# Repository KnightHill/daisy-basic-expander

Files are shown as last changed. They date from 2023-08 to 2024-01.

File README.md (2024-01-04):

# ElectroSmith POD basic expander

[ElectroSmith POD](https://www.electro-smith.com/daisy/pod)

Adds two potentiometers and six buttons to the pod. Check the included KiCad 7 [schematics](hardware) for details.

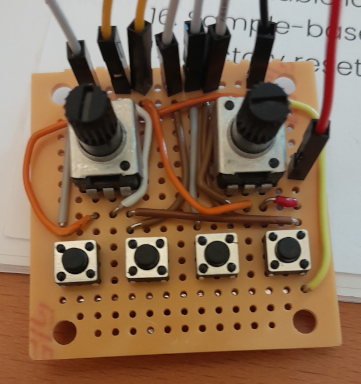
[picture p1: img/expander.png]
Expander bread board


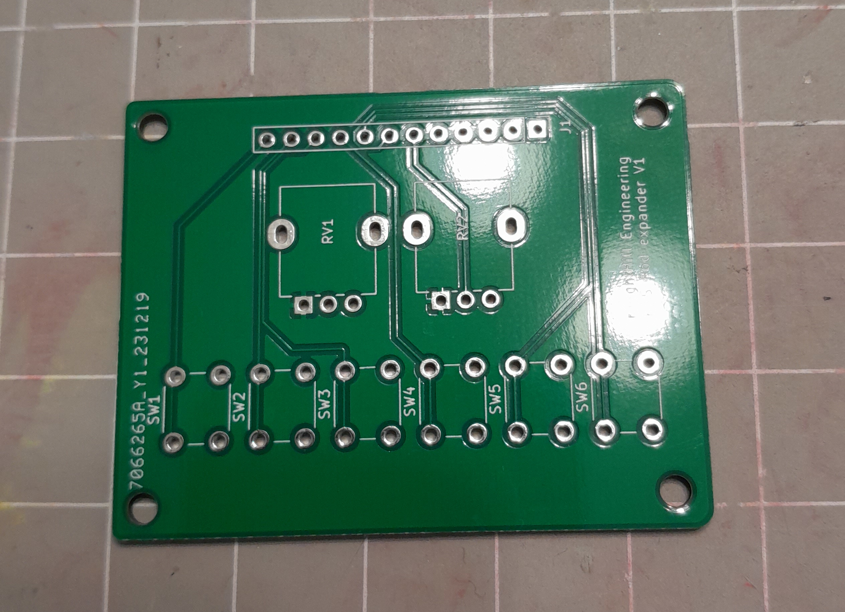
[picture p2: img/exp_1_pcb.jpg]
Expander v1 PCB


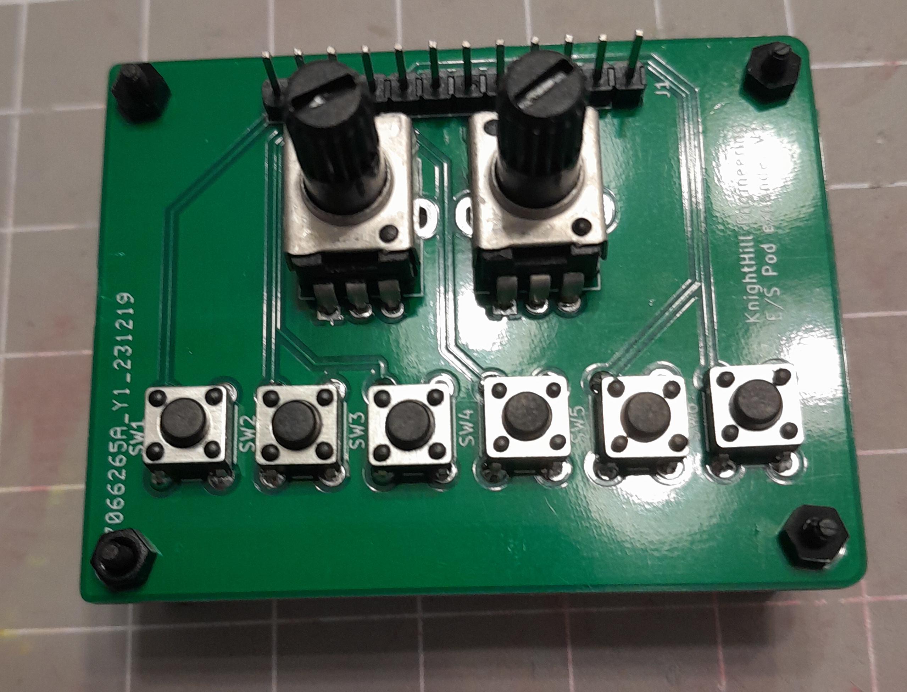
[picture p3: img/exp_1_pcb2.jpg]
Expander v1


 # Disclamer

This is a hobby project. I accept no responsibility for damage to you Daisy Seed, external equipment or anything else. You use this code and harware at your own risk.

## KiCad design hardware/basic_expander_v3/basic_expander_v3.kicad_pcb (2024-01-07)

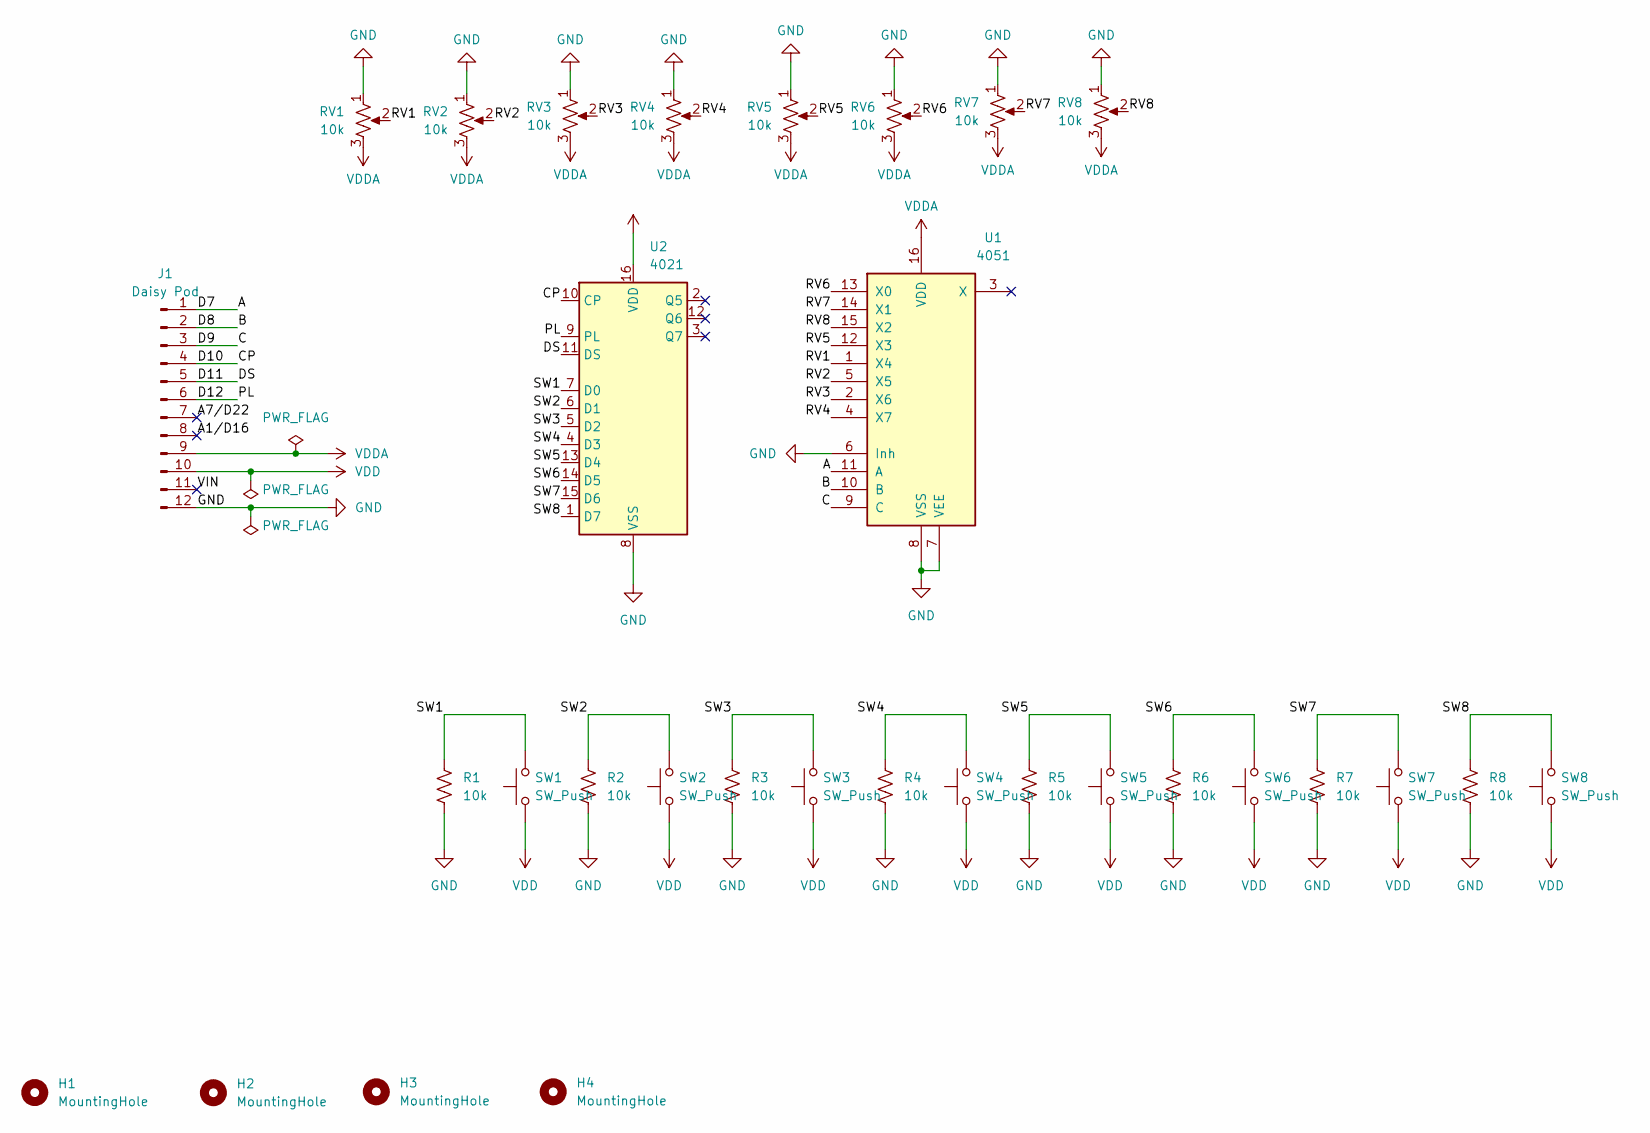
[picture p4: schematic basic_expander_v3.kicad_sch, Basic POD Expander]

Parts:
H1, H2, H3, H4: MountingHole; MountingHole_2.2mm_M2
J1: Daisy Pod; PinHeader_1x12_P2.54mm_Vertical
R1, R2, R3, R4, R5, R6, R7, R8: 10k; R_Axial_DIN0207_L6.3mm_D2.5mm_P7.62mm_Horizontal
RV1, RV2, RV3, RV4, RV5, RV6, RV7, RV8: 10k; Potentiometer_Alpha_RD901F-40-00D_Single_Vertical
SW1, SW2, SW3, SW4, SW5, SW6, SW7, SW8: SW_Push; SW_PUSH_6mm
U1: 4051; DIP-16_W7.62mm
U2: 4021; DIP-16_W7.62mm

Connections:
/A: J1.1, U1.11 (A)
/A1/D16: J1.8
/A7/D22: J1.7
/B: J1.2, U1.10 (B)
/C: J1.3, U1.9 (C)
/CP: J1.4, U2.10 (CP)
/D11: J1.5, U2.11 (DS)
/D12: J1.6, U2.9 (PL)
/RV1: RV1.2, U1.1 (X4)
/RV2: RV2.2, U1.5 (X5)
/RV3: RV3.2, U1.2 (X6)
/RV4: RV4.2, U1.4 (X7)
/RV5: RV5.2, U1.12 (X3)
/RV6: RV6.2, U1.13 (X0)
/RV7: RV7.2, U1.14 (X1)
/RV8: RV8.2, U1.15 (X2)
/SW1: R1.1, SW1.2, U2.7 (D0)
/SW2: R2.1, SW2.2, U2.6 (D1)
/SW3: R3.1, SW3.2, U2.5 (D2)
/SW4: R4.1, SW4.2, U2.4 (D3)
/SW5: R5.1, SW5.2, U2.13 (D4)
/SW6: R6.1, SW6.2, U2.14 (D5)
/SW7: R7.1, SW7.2, U2.15 (D6)
/SW8: R8.1, SW8.2, U2.1 (D7)
/VIN: J1.11
GND: J1.12, R1.2, R2.2, R3.2, R4.2, R5.2, R6.2, R7.2, R8.2, RV1.1, RV2.1, RV3.1, RV4.1, RV5.1, RV6.1, RV7.1, RV8.1, U1.6 (Inh), U1.7 (VEE), U1.8 (VSS), U2.8 (VSS)
VDD: J1.10, SW1.1, SW2.1, SW3.1, SW4.1, SW5.1, SW6.1, SW7.1, SW8.1, U2.16 (VDD)
VDDA: J1.9, RV1.3, RV2.3, RV3.3, RV4.3, RV5.3, RV6.3, RV7.3, RV8.3, U1.16 (VDD)

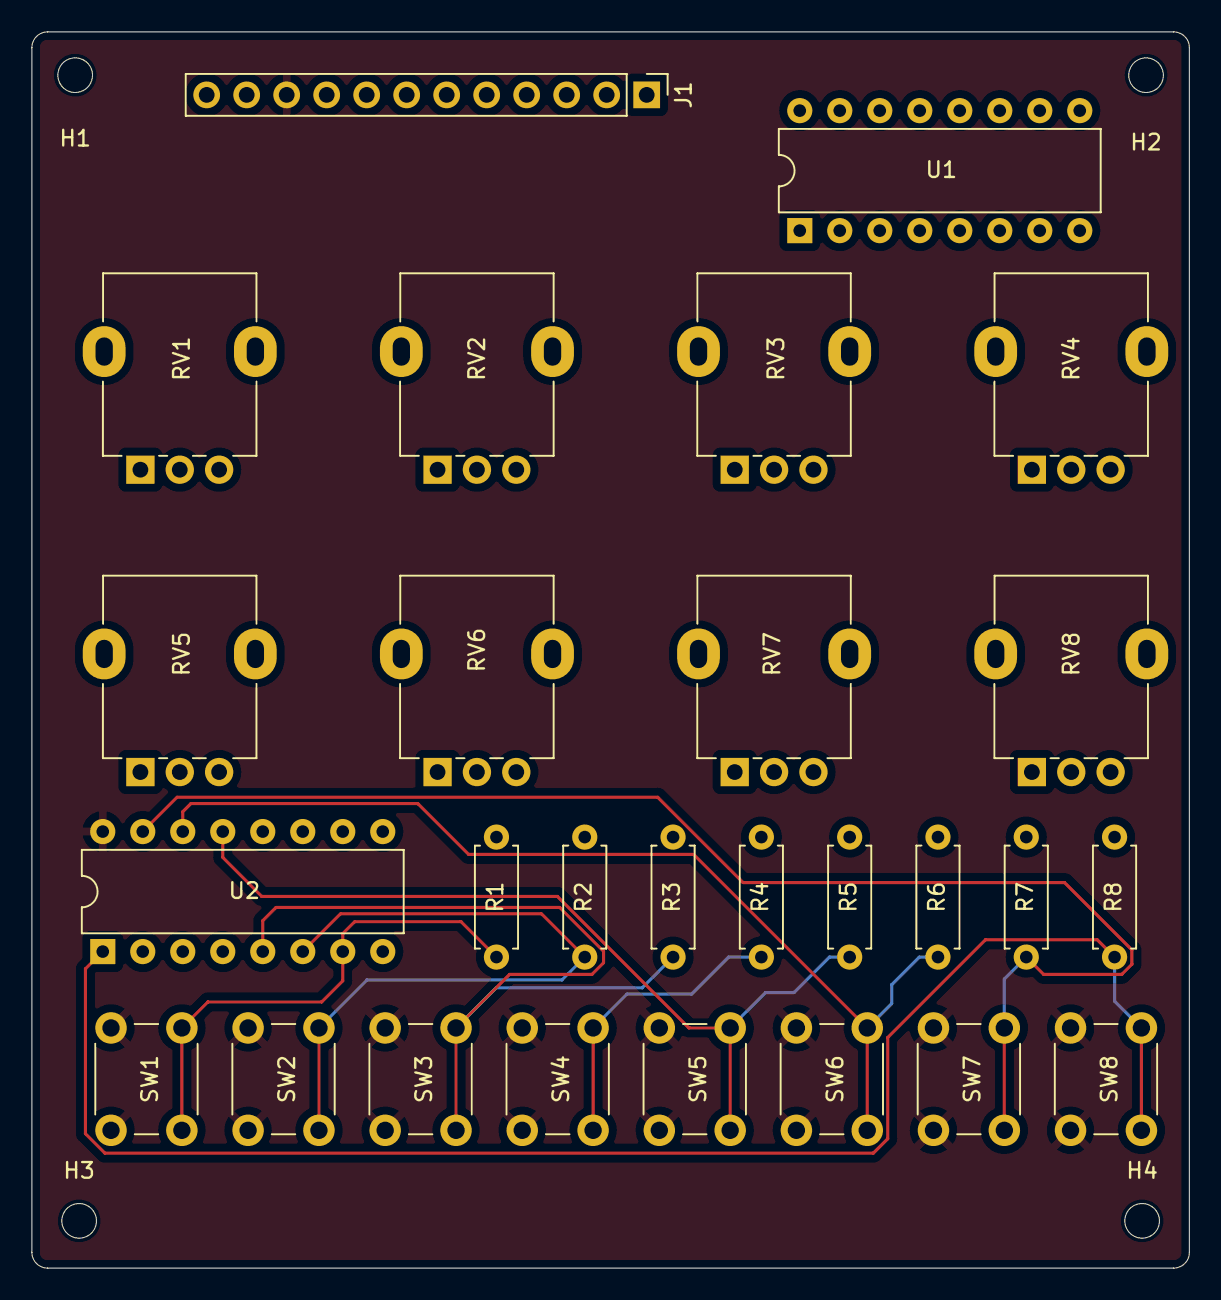
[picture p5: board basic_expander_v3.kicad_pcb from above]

Board: 2 copper layers, 73.5 x 78.5 mm, 31 parts (0 on the bottom side), 25 nets.

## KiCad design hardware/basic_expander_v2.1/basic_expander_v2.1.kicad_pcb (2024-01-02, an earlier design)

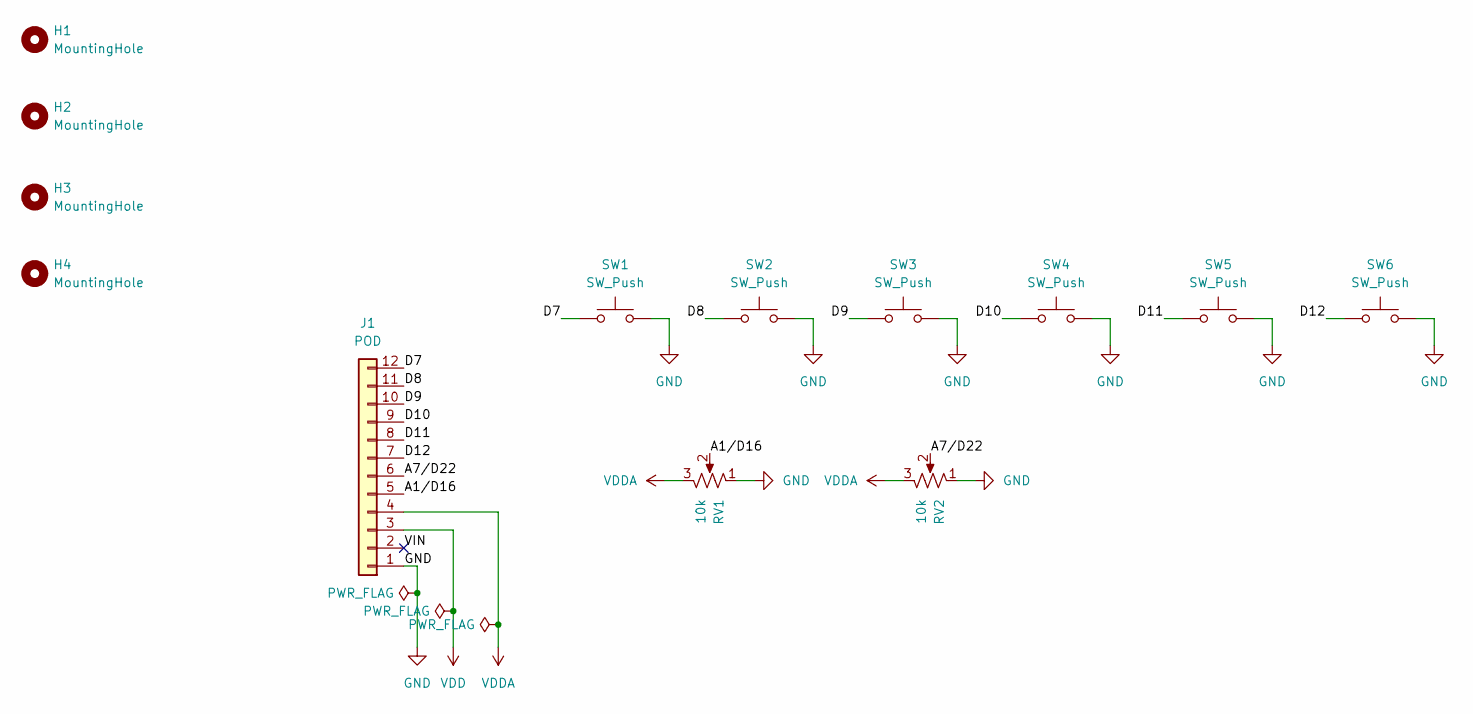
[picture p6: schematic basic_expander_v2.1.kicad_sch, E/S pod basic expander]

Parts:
H1, H2, H3, H4: MountingHole; MountingHole_2.2mm_M2
J1: POD; PinHeader_1x12_P2.54mm_Vertical
RV1, RV2: 10k; Potentiometer_uxcel_9mm_Single_Vertical
SW1, SW2, SW3, SW4, SW5, SW6: SW_Push; SW_PUSH_6mm

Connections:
/A1/D16: J1.5, RV1.2
/A7/D22: J1.6, RV2.2
/D7: J1.12, SW1.1
/D8: J1.11, SW2.1
/D9: J1.10, SW3.1
/D10: J1.9, SW4.1
/D11: J1.8, SW5.1
/D12: J1.7, SW6.1
/VIN: J1.2
GND: J1.1, RV1.1, RV2.1, SW1.2, SW2.2, SW3.2, SW4.2, SW5.2, SW6.2
VDD: J1.3
VDDA: J1.4, RV1.3, RV2.3

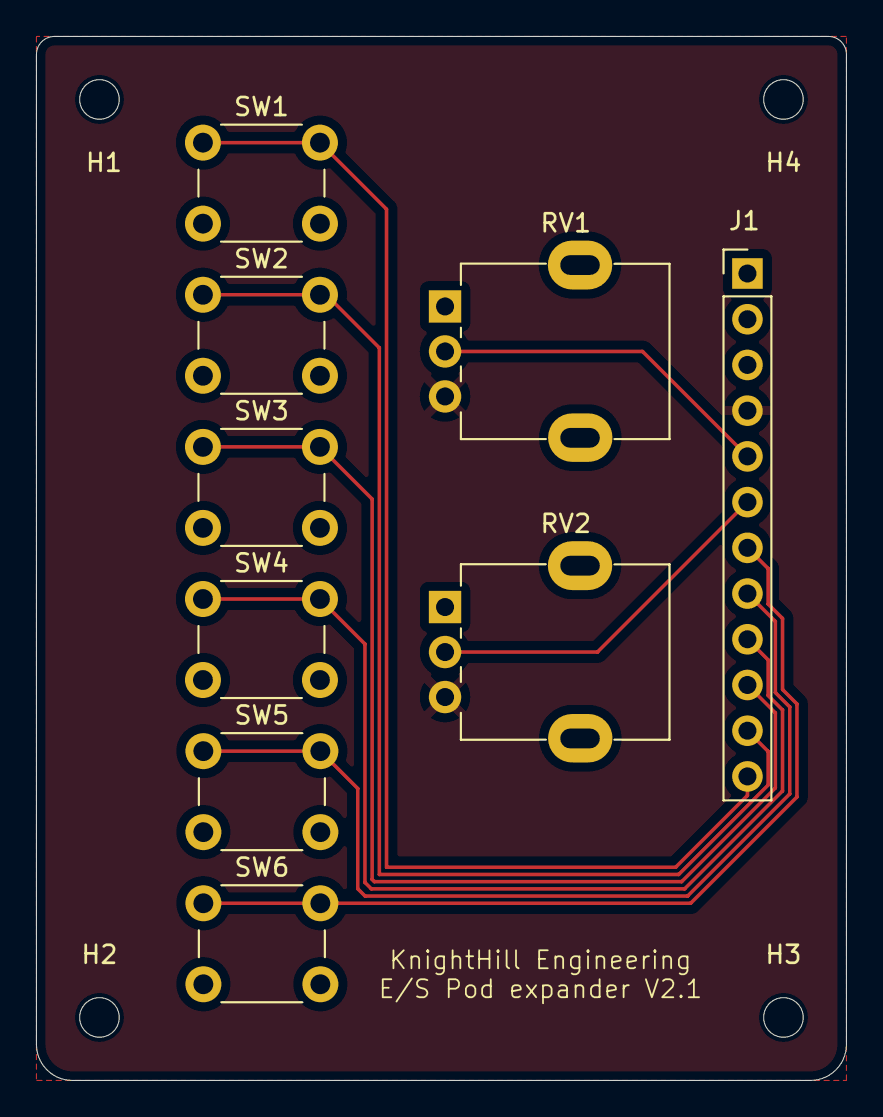
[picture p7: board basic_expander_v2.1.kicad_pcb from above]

Board: 2 copper layers, 45.0 x 58.0 mm, 13 parts (0 on the bottom side), 10 nets.

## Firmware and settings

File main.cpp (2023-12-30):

#include "basic_exp.h"

using namespace daisy;

static BasicExp hw;

bool led1, led2, led3, led4, led5, led6, led7, led8;

struct RGB {
  float R, G, B;
};

void BlinkLEDColor(RGB rgb, int delay)
{
  hw.led1.Set(rgb.R, rgb.G, rgb.B);
  hw.UpdateLeds();
  System::Delay(delay);
}

void BlinkLED(RGB rgb, int delay = 150)
{
  for (size_t i = 0; i < 3; i++) {
    BlinkLEDColor(rgb, delay);
    BlinkLEDColor({0, 0, 0}, delay);
  }
}

int main()
{
  hw.Init();
  hw.SetAudioBlockSize(4);
  hw.StartAdc();

  led1 = led2 = led3 = led4 = led5 = led6 = led7 = led8 = false;

  // initialize the logger
  hw.seed.StartLog(false);

  BlinkLED({1, 1, 1});

  while (1) {
    System::Delay(10);
    hw.ProcessAnalogControls();
    hw.ProcessDigitalControls();

    float knob1 = hw.knob1.Process();
    float knob2 = hw.knob2.Process();
    float knob3 = hw.knob3.Process();
    float knob4 = hw.knob4.Process();

    if (hw.button1.RisingEdge())
      led1 = !led1;

    if (hw.button2.RisingEdge())
      led2 = !led2;

    if (hw.button3.RisingEdge())
      led3 = !led3;

    if (hw.button4.RisingEdge())
      led4 = !led4;

    if (hw.button5.RisingEdge())
      led5 = !led5;

    if (hw.button6.RisingEdge())
      led6 = !led6;

    if (hw.button7.RisingEdge())
      led7 = !led7;

    if (hw.button8.RisingEdge())
      led8 = !led8;

    hw.seed.PrintLine("k1: %f k2: %f k3: %f k4: %f", knob1, knob2, knob3, knob4);
    hw.seed.PrintLine("sw1: %d sw2: %d sw3: %d sw4: %d sw5: %d sw6: %d sw7: %d sw8: %d ", led1, led2, led3, led4, led5, led6, led7, led8);
  }
}

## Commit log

2023-08-27 add schematic
    [pod_basic_expander.kicad_pcb, pod_basic_expander.kicad_sch]
2023-08-31 Improve schematic
    [pod_basic_expander.kicad_pcb, pod_basic_expander.kicad_sch]
2023-12-06 PCB changes
    [pod_basic_expander.kicad_pcb, pod_basic_expander.kicad_sch, pod_basic_expander_2.kicad_pcb]
2023-12-07 pcd changes
    [pod_basic_expander.kicad_pcb]
2023-12-19 Add gerber/drill files
    [pod_basic_expander2-B_Cu.gbl, pod_basic_expander2-B_Mask.gbs, pod_basic_expander2-B_Paste.gbp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]
2023-12-19 gerber files cleanup
    [pod_basic_expander2-NPTH-drl_map.gbr, pod_basic_expander2-NPTH.drl, pod_basic_expander2-PTH-drl_map.gbr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]
2023-12-25 add v3 pcb
    [basic_expander_v3.kicad_pcb, basic_expander_v3.kicad_sch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]
2023-12-30 add two more buttons
2023-12-30 switch knob 3 and 4
2023-12-30 add pcb v2.1
    [basic_expander_v2.1-B_Cu.gbl, basic_expander_v2.1-B_Mask.gbs, basic_expander_v2.1-B_Paste.gbp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]
2023-12-30 remove old files
    [basic_expander_v2.1-B_Cu.gbl, basic_expander_v2.1-B_Mask.gbs, basic_expander_v2.1-B_Paste.gbp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]
2024-01-02 fix pots orientation
    [basic_expander_v2.1.kicad_pcb, basic_expander_v2.1.kicad_sch]
2024-01-02 add v2.1 gerber files
    [basic_expander_v2.1-B_Cu.gbl, basic_expander_v2.1-B_Mask.gbs, basic_expander_v2.1-B_Paste.gbp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]
2024-01-03 add v3 files
    [basic_expander_v3.kicad_pcb, basic_expander_v3.kicad_sch]
2024-01-03 add 4 pots
    [basic_expander_v3.kicad_pcb, basic_expander_v3.kicad_sch]
2024-01-07 add license
    [basic_expander_v3.kicad_pcb]
